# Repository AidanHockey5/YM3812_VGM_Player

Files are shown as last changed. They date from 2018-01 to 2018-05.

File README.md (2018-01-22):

# YM3812_VGM_Player
A Video Game Music player based on the YM3812 (OPL2) and Teensy 3.5.

You can view this project in action here:
https://www.youtube.com/watch?v=aLaUDFnNqQc

# Information about the main sound chips and VGM

The YM3812, AKA OPL2 was a staple FM soundchip of the early 1990's. It claim to fame was its inclusion on the Adlib and Soundblaster soundcards. OPL2 is THE FM sound of 1990's PC gaming.

VGM stands for Video Game Music, and it is a 44.1KHz logging format that stores real soundchip register information. My player will parse these files and send the data to the appropriate chips. You can learn more about the VGM file format here: http://www.smspower.org/Music/VGMFileFormat

http://www.smspower.org/uploads/Music/vgmspec170.txt?sid=58da937e68300c059412b536d4db2ca0

# Hook-up Guide

Teensy 3.5 | YM
------------ | -------------
23, 22, 21...17, 16 | D0-D7
34  | CS
33 | RD
32 | WR
31 | A0
30 | IC
29 | IRQ

The YM3812 requires a 3.579545 MHz signal to function properly. I just used a full-can crystal for this, but any clock source of that speed will work.
You will also need a Y3014B DAC IC along with an OP-amp (LM358).

# SD Card Information
The Teensy 3.5 has a built-in, high speed micro-SD card reader. You must format your SD card to Fat32 in order for this device to work correctly. Your SD card must only contain uncompressed .vgm files. VGZ FILES WILL NOT WORK! You may download .vgz files and use [7zip](http://www.7-zip.org/download.html) to extract the uncompressed file out of them. Vgm files on the SD card do not need to have the .vgm extension. As long as they contain valid, uncompressed vgm data, they will be read by the program regardless of their name.
You can find VGM files by Googling "myGameName VGM," or by checking out sites like http://vgmrips.net/packs/

# Control Over Serial
You can use a serial connection to control playback features. The commands are as follows:

Command | Result
------------ | -------------
\+ | Next Track
\- | Previous Track
\* | Random Track
\/ | Toggle Shuffle Mode
\. | Toggle Song Looping
r: | Request song

A song request is formatted as follows: ```r:mySongFile.vgm```
Once a song request is sent through the serial console, an attempt will be made to open that song file. The file must exist on the Teensy's SD card, and spelling/capitalization must be correct.
Need an easy-to-use serial console? [I've made one here.](https://github.com/AidanHockey5/OpenArduinoSerialConsole)

# Schematic
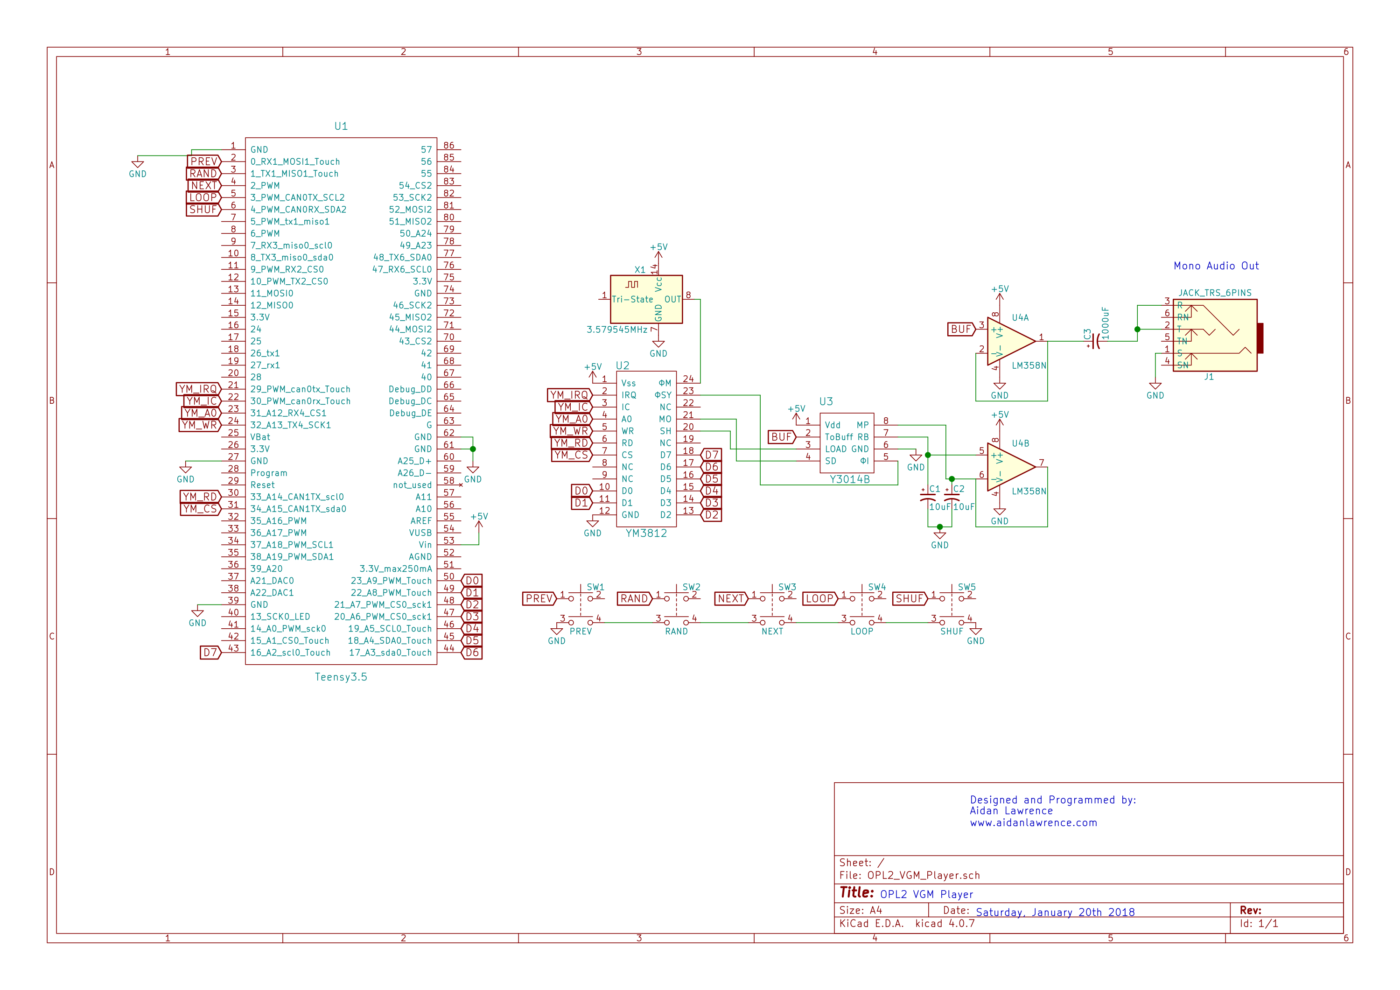
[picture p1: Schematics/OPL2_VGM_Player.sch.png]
Schematic


[PDF](https://github.com/AidanHockey5/YM3812_VGM_Player/raw/master/Schematics/OPL2_VGM_Player.pdf)

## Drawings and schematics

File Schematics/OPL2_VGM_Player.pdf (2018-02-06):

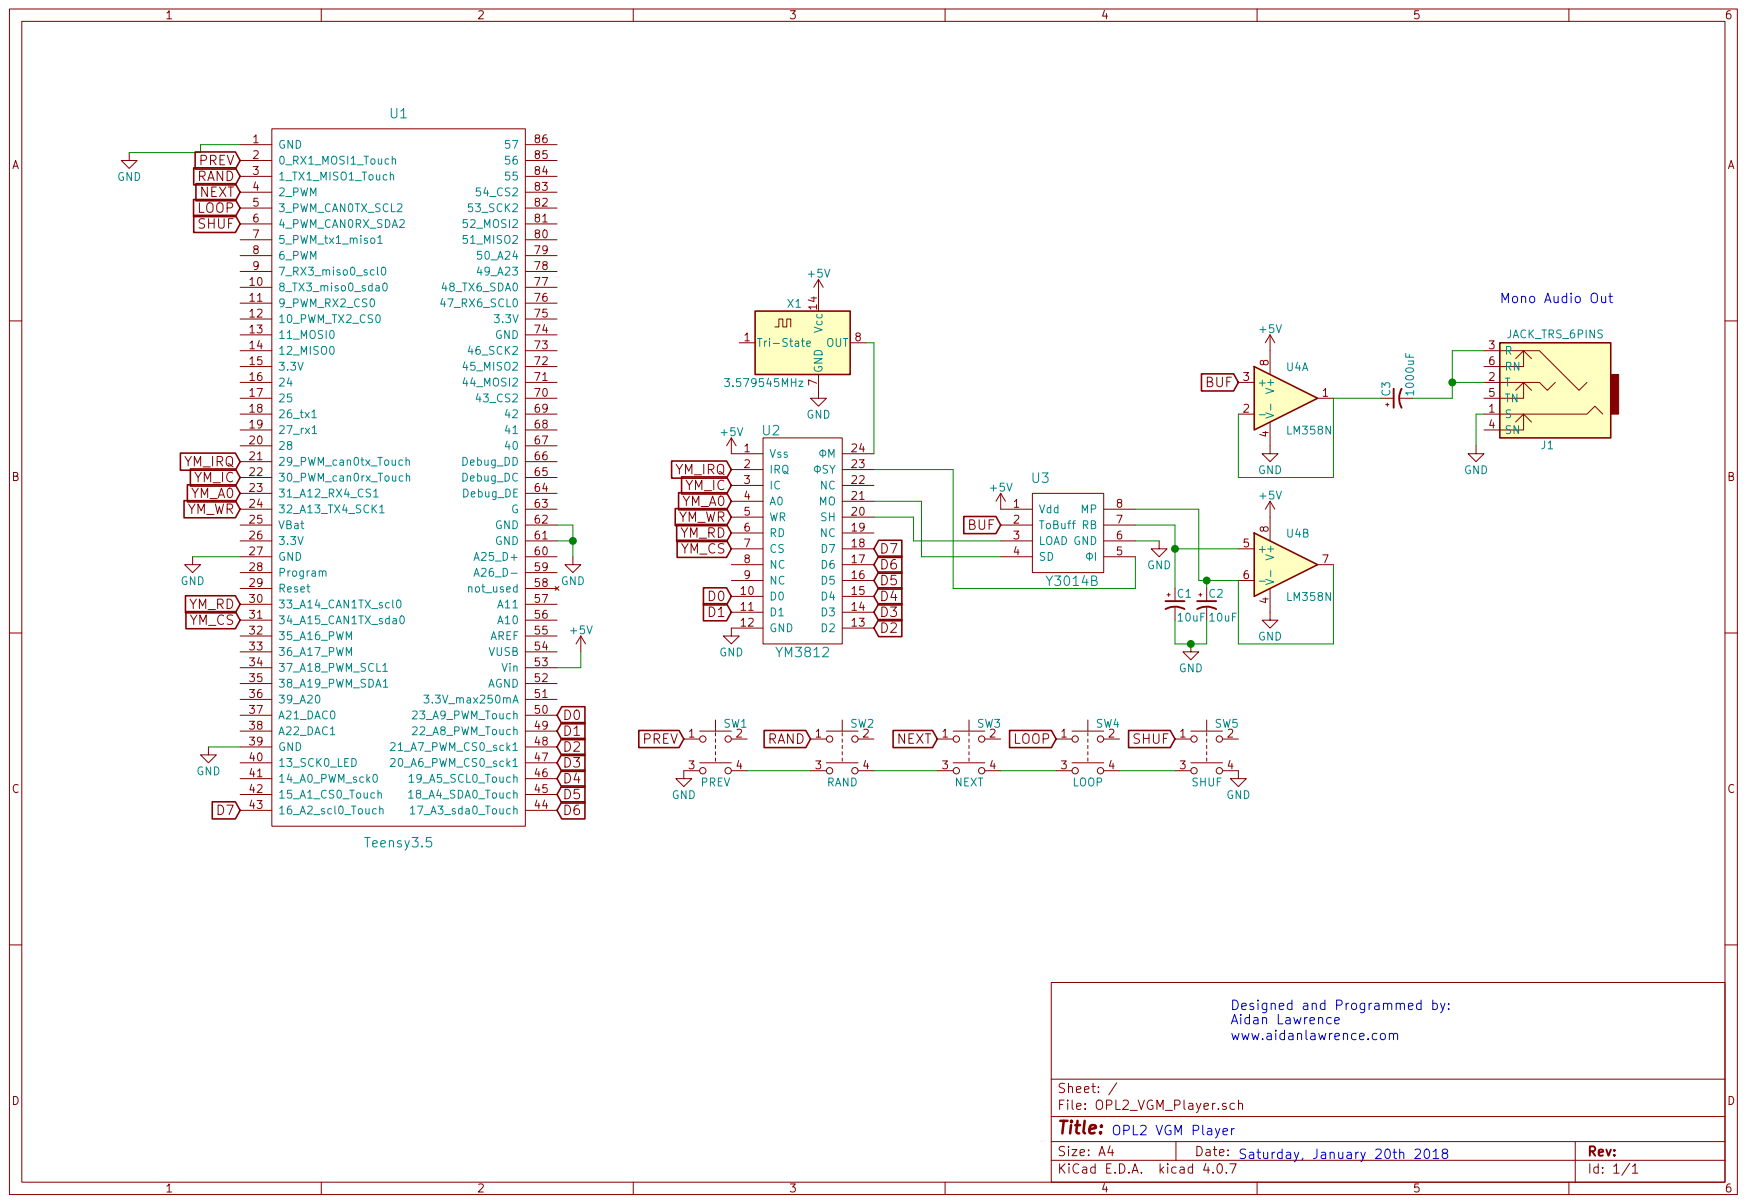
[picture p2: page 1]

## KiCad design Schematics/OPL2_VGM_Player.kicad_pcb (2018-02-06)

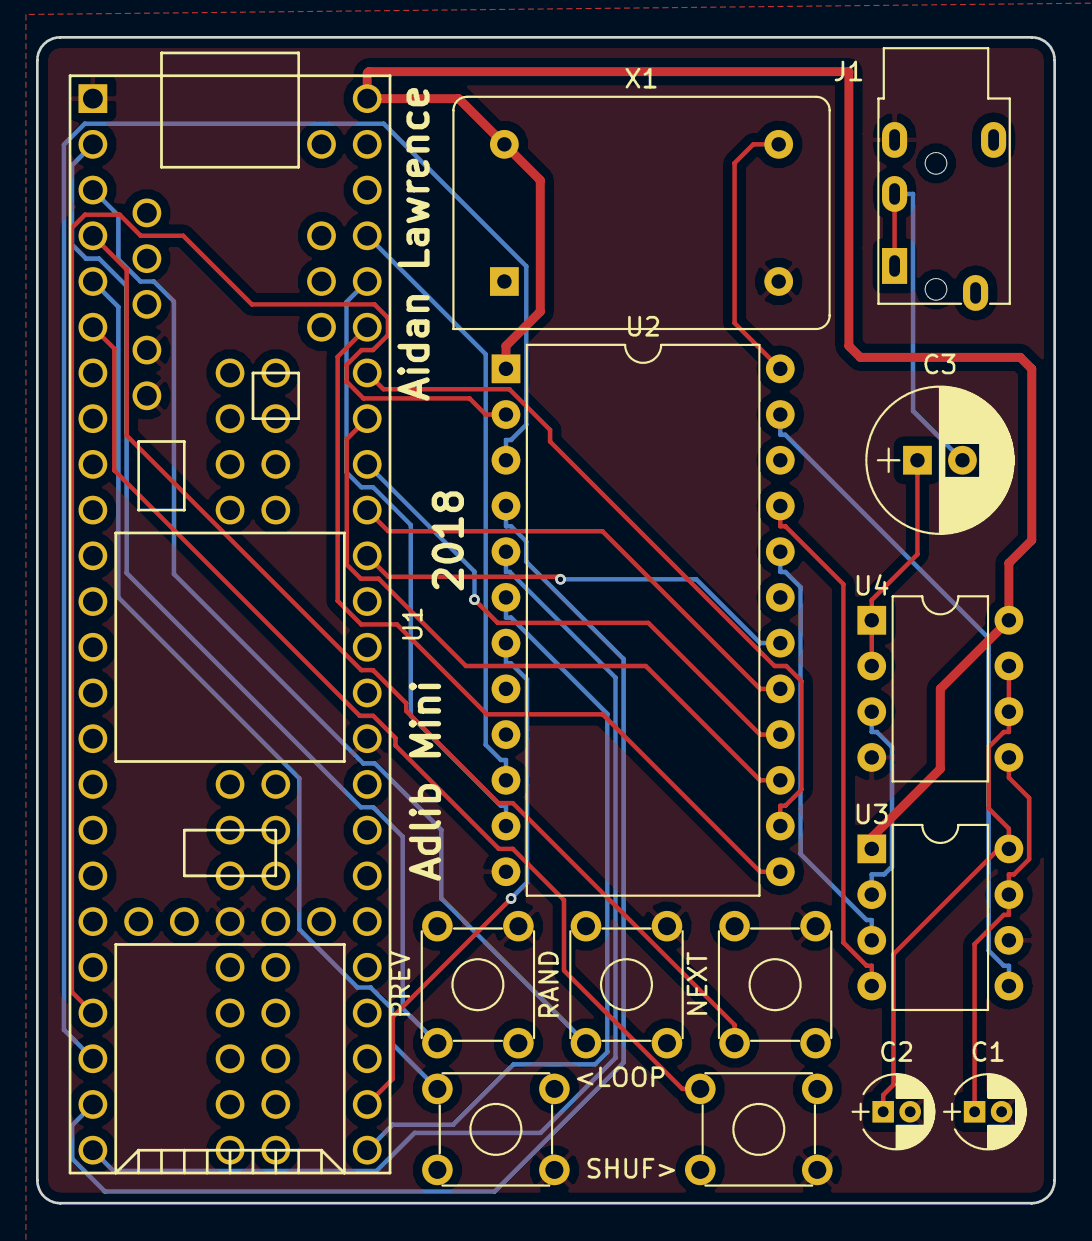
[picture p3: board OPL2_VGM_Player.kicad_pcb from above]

Board: 2 copper layers, 56.5 x 64.8 mm, 14 parts (0 on the bottom side), 30 nets.

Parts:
<LOOP: LOOP; SW_TH_Tactile_Omron_B3F-10xx
C1, C2: 10uF; CP_Radial_D4.0mm_P1.50mm
C3: 1000uF; CP_Radial_D8.0mm_P2.50mm
J1: JACK_TRS_6PINS; PJ320E_3.5mm_Jack
NEXT: NEXT; SW_TH_Tactile_Omron_B3F-10xx
PREV: PREV; SW_TH_Tactile_Omron_B3F-10xx
RAND: RAND; SW_TH_Tactile_Omron_B3F-10xx
SHUF>: SHUF; SW_TH_Tactile_Omron_B3F-10xx
U1: Teensy3.5; Teensy35_36
U2: YM3812; DIP-24_W15.24mm
U3: Y3014B; DIP-8_W7.62mm
U4: LM358N; DIP-8_W7.62mm
X1: 3.579545MHz; Oscillator_DIP-14

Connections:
+5V: U1.53, U2.1, U3.1, U4.8, X1.14
BUF: U3.2, U4.3
D0: U1.50, U2.10
D1: U1.49, U2.11
D2: U1.48, U2.13
D3: U1.47, U2.14
D4: U1.46, U2.15
D5: U1.45, U2.16
D6: U1.44, U2.17
D7: U1.43, U2.18
GND: <LOOP.4, C1.2, C2.2, J1.3, NEXT.4, PREV.4, RAND.4, SHUF>.4, U1.1, U1.27, U1.39, U1.61, U1.62, U2.12, U3.6, U4.4, X1.7
LOOP: <LOOP.1, U1.5
NEXT: NEXT.1, U1.4
unnamed: C1.1, U3.7, U4.5
unnamed: C2.1, U3.8, U4.6, U4.7
unnamed: C3.1, U4.1, U4.2
unnamed: C3.2, J1.1, J1.2
unnamed: U2.20, U3.3
unnamed: U2.21, U3.4
unnamed: U2.23, U3.5
unnamed: U2.24, X1.8
PREV: PREV.1, U1.2
RAND: RAND.1, U1.3
SHUF: SHUF>.1, U1.6
YM_A0: U1.23, U2.4
YM_CS: U1.31, U2.7
YM_IC: U1.22, U2.3
YM_IRQ: U1.21, U2.2
YM_RD: U1.30, U2.6
YM_WR: U1.24, U2.5

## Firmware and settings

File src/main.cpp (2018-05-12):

#include <Arduino.h>
#include "SdFat.h"
#include "YM3812.h"

int YM_Datapins[8] = {23, 22, 21, 20, 19, 18, 17, 16};

const int YM_CS = 34;
const int YM_RD = 33;
const int YM_WR = 32;
const int YM_A0 = 31;
const int YM_IC = 30; 
const int YM_IRQ = 29;

YM3812 ym3812(YM_Datapins, YM_CS, YM_RD, YM_WR, YM_A0, YM_IRQ, YM_IC);

const int prev_btn = 0;
const int rand_btn = 1;
const int next_btn = 2;
const int loop_btn = 3;
const int shuf_btn = 4;

SdFatSdio SD;
File vgm;

//Buffer & file stream
const unsigned int MAX_CMD_BUFFER = 1;
unsigned char cmdBuffer[MAX_CMD_BUFFER];
uint32_t bufferPos = 0;
const unsigned int MAX_FILE_NAME_SIZE = 1024;
char fileName[MAX_FILE_NAME_SIZE];
unsigned char cmd = 0;
uint16_t numberOfFiles = 0;
int32_t currentFileNumber = 0;


//Timing Variables
float singleSampleWait = 0;
const int sampleRate = 44100; //44100 standard
const float WAIT60TH = ((1000.0 / (sampleRate/(float)735))*1000);
const float WAIT50TH = ((1000.0 / (sampleRate/(float)882))*1000);
uint32_t waitSamples = 0;
unsigned long preCalced8nDelays[16];
unsigned long preCalced7nDelays[16];
unsigned long lastWaitData61 = 0;
unsigned long cachedWaitTime61 = 0;
unsigned long pauseTime = 0;
unsigned long startTime = 0;

//Song Data Variables
uint32_t loopOffset = 0;
uint16_t loopCount = 0;
uint16_t nextSongAfterXLoops = 3;
enum PlayMode {LOOP, PAUSE, SHUFFLE, IN_ORDER};
PlayMode playMode = SHUFFLE;

//GD3 Data
String trackTitle;
String gameName;
String systemName;
String gameDate;


void FillBuffer()
{
    vgm.readBytes(cmdBuffer, MAX_CMD_BUFFER);
    //Serial.print("File location: "); Serial.println(vgm.position(), HEX);
}

unsigned char GetByte()
{
  if(bufferPos == MAX_CMD_BUFFER)
  {
    bufferPos = 0;
    FillBuffer();
  }
  return cmdBuffer[bufferPos++];
}

uint32_t ReadBuffer32() //Read 32 bit value from buffer
{
  byte v0 = GetByte();
  byte v1 = GetByte();
  byte v2 = GetByte();
  byte v3 = GetByte();
  return uint32_t(v0 + (v1 << 8) + (v2 << 16) + (v3 << 24));
}

uint32_t ReadSD32() //Read 32 bit value straight from SD card
{
  byte v0 = vgm.read();
  byte v1 = vgm.read();
  byte v2 = vgm.read();
  byte v3 = vgm.read();
  return uint32_t(v0 + (v1 << 8) + (v2 << 16) + (v3 << 24));
}

void ClearBuffers()
{
  bufferPos = 0;
  for(int i = 0; i < MAX_CMD_BUFFER; i++)
    cmdBuffer[i] = 0;
}

void RemoveSVI() //Sometimes, Windows likes to place invisible files in our SD card without asking... GTFO!
{
  File nextFile;
  nextFile.openNext(SD.vwd(), O_READ);
  char name[MAX_FILE_NAME_SIZE];
  nextFile.getName(name, MAX_FILE_NAME_SIZE);
  String n = String(name);
  if(n == "System Volume Information")
  {
      if(!nextFile.rmRfStar())
        Serial.println("Failed to remove SVI file");
  }
  SD.vwd()->rewind();
  nextFile.close();
}

void ClearTrackData()
{
  for(int i = 0; i < MAX_FILE_NAME_SIZE; i++)
    fileName[i] = 0;
  trackTitle = "";
  gameName = "";
  systemName = "";
  gameDate = "";
}

uint32_t EoFOffset = 0;
uint32_t VGMVersion = 0;
uint32_t GD3Offset = 0;
void GetHeaderData() //Scrape off the important VGM data from the header, then drop down to the GD3 area for song info data
{
  ReadBuffer32(); //V - G - M 0x00->0x03
  EoFOffset = ReadBuffer32(); //End of File offset 0x04->0x07
  VGMVersion = ReadBuffer32(); //VGM Version 0x08->0x0B
  for(int i = 0x0C; i<0x14; i++)GetByte(); //Skip 0x0C->0x14
  GD3Offset = ReadBuffer32(); //GD3 (song info) data offset 0x14->0x17

  uint32_t bufferReturnPosition = vgm.position();
  vgm.seek(0);
  vgm.seekCur(GD3Offset+0x14);
  uint32_t GD3Position = 0x00;
  ReadSD32(); GD3Position+=4;  //G - D - 3
  ReadSD32(); GD3Position+=4;  //Version data
  uint32_t dataLength = ReadSD32(); //Get size of data payload
  GD3Position+=4;

  String rawGD3String;
  // Serial.print("DATA LENGTH: ");
  // Serial.println(dataLength);

  for(int i = 0; i<dataLength; i++) //Convert 16-bit characters to 8 bit chars. This may cause issues with non ASCII characters. (IE Japanese chars.)
  {
    char c1 = vgm.read();
    char c2 = vgm.read();
    if(c1 == 0 && c2 == 0)
      rawGD3String += '\n';
    else
      rawGD3String += char(c1);
  }
  GD3Position = 0;

  while(rawGD3String[GD3Position] != '\n') //Parse out the track title.
  {
    trackTitle += rawGD3String[GD3Position];
    GD3Position++;
  }
  GD3Position++;

  while(rawGD3String[GD3Position] != '\n') GD3Position++; //Skip Japanese track title.
  GD3Position++;
  while(rawGD3String[GD3Position] != '\n') //Parse out the game name.
  {
    gameName += rawGD3String[GD3Position];
    GD3Position++;
  }
  GD3Position++;
  while(rawGD3String[GD3Position] != '\n') GD3Position++;//Skip Japanese game name.
  GD3Position++;
  while(rawGD3String[GD3Position] != '\n') //Parse out the system name.
  {
    systemName += rawGD3String[GD3Position];
    GD3Position++;
  }
  GD3Position++;
  while(rawGD3String[GD3Position] != '\n') GD3Position++;//Skip Japanese system name.
  GD3Position++;
  while(rawGD3String[GD3Position] != '\n') GD3Position++;//Skip English authors
  GD3Position++;
  // while(rawGD3String[GD3Position] != 0) //Parse out the music authors (I skipped this since it sometimes produces a ton of data! Uncomment this, comment skip, add vars if you want this.)
  // {
  //   musicAuthors += rawGD3String[GD3Position];
  //   GD3Position++;
  // }
  while(rawGD3String[GD3Position] != '\n') GD3Position++;//Skip Japanese authors.
  GD3Position++;
  while(rawGD3String[GD3Position] != '\n') //Parse out the game date
  {
    gameDate += rawGD3String[GD3Position];
    GD3Position++;
  }
  GD3Position++;
  Serial.println(trackTitle);
  Serial.println(gameName);
  Serial.println(systemName);
  Serial.println(gameDate);
  Serial.println("");
  vgm.seek(bufferReturnPosition); //Send the file seek back to the original buffer position so we don't confuse our program.
  waitSamples = ReadBuffer32(); //0x18->0x1B : Get wait Samples count
  loopOffset = ReadBuffer32();  //0x1C->0x1F : Get loop offset Postition
  for(int i = 0; i<5; i++) ReadBuffer32(); //Skip right to the VGM data offset position;
  uint32_t vgmDataOffset = ReadBuffer32();
  if(vgmDataOffset == 0 || vgmDataOffset == 12) //VGM starts at standard 0x40
  {
    ReadBuffer32(); ReadBuffer32();
  }
  else
  {
    for(int i = 0; i < vgmDataOffset-4; i++) GetByte();  //VGM starts at different data position (Probably VGM spec 1.7+)
  }
  //Offset manually set to -4 due to overshooting the data offset. This does not seem normal and will need to be fixed.
  //Serial.println("Starting postion: "); Serial.println(vgm.position(), HEX);
}

enum StartUpProfile {FIRST_START, NEXT, PREVIOUS, RNG, REQUEST};
void StartupSequence(StartUpProfile sup, String request = "")
{
  File nextFile;
  ClearTrackData();
  switch(sup)
  {
    case FIRST_START:
    {
      nextFile.openNext(SD.vwd(), O_READ);
      nextFile.getName(fileName, MAX_FILE_NAME_SIZE);
      nextFile.close();
      currentFileNumber = 0;
    }
    break;
    case NEXT:
    {
      if(currentFileNumber+1 >= numberOfFiles)
      {
          SD.vwd()->rewind();
          currentFileNumber = 0;
      }
      else
          currentFileNumber++;
      nextFile.openNext(SD.vwd(), O_READ);
      nextFile.getName(fileName, MAX_FILE_NAME_SIZE);
      nextFile.close();
    }
    break;
    case PREVIOUS:
    {
      if(currentFileNumber != 0)
      {
        currentFileNumber--;
        SD.vwd()->rewind();
        for(int i = 0; i<=currentFileNumber; i++)
        {
          nextFile.close();
          nextFile.openNext(SD.vwd(), O_READ);
        }
        nextFile.getName(fileName, MAX_FILE_NAME_SIZE);
        nextFile.close();
      }
      else
      {
        currentFileNumber = numberOfFiles-1;
        SD.vwd()->rewind();
        for(int i = 0; i<=currentFileNumber; i++)
        {
          nextFile.close();
          nextFile.openNext(SD.vwd(), O_READ);
        }
        nextFile.getName(fileName, MAX_FILE_NAME_SIZE);
        nextFile.close();
      }
    }
    break;
    case RNG:
    {
      randomSeed(micros());
      uint16_t randomFile = currentFileNumber;
      while(randomFile == currentFileNumber)
        randomFile = random(numberOfFiles-1);
      currentFileNumber = randomFile;
      SD.vwd()->rewind();
      nextFile.openNext(SD.vwd(), O_READ);
      {
        for(int i = 0; i<randomFile; i++)
        {
          nextFile.close();
          nextFile.openNext(SD.vwd(), O_READ);
        }
      }
      nextFile.getName(fileName, MAX_FILE_NAME_SIZE);
      nextFile.close();
    }
    break;
    case REQUEST:
    {
      SD.vwd()->rewind();
      bool fileFound = false;
      Serial.print("REQUEST: ");Serial.println(request);
      for(int i = 0; i<numberOfFiles; i++)
      {
        nextFile.close();
        nextFile.openNext(SD.vwd(), O_READ);
        nextFile.getName(fileName, MAX_FILE_NAME_SIZE);
        String tmpFN = String(fileName);
        tmpFN.trim();
        if(tmpFN == request.trim())
        {
          currentFileNumber = i;
          fileFound = true;
          break;
        }
      }
      nextFile.close();
      if(fileFound)
      {
        Serial.println("File found!");
      }
      else
      {
        Serial.println("ERROR: File not found! Continuing with current song.");
        return;
      }
    }
    break;
  }
  ym3812.Reset();
  waitSamples = 0;
  loopOffset = 0;
  lastWaitData61 = 0;
  cachedWaitTime61 = 0;
  pauseTime = 0;
  startTime = 0;
  loopCount = 0;
  cmd = 0;
  ClearBuffers();
  Serial.print("Current file number: "); Serial.print(currentFileNumber+1); Serial.print("/"); Serial.println(numberOfFiles);
  if(vgm.isOpen())
    vgm.close();
  vgm = SD.open(fileName, FILE_READ);
  if(!vgm)
    Serial.println("File open failed!");
  else
    Serial.println("Opened successfully...");
  FillBuffer();
  GetHeaderData();
  singleSampleWait = ((1000.0 / (sampleRate/(float)1))*1000);

    for(int i = 0; i<16; i++)
    {
      if(i == 0)
      {
        preCalced8nDelays[i] = 0;
        preCalced7nDelays[i] = 1;
      }
      else
      {
        preCalced8nDelays[i] = ((1000.0 / (sampleRate/(float)i))*1000);
        preCalced7nDelays[i] = ((1000.0 / (sampleRate/(float)i+1))*1000);
      }
    }
    delay(1000);
}

void setup()
{
    pinMode(prev_btn, INPUT_PULLUP);
    pinMode(rand_btn, INPUT_PULLUP);
    pinMode(next_btn, INPUT_PULLUP);
    pinMode(loop_btn, INPUT_PULLUP);
    pinMode(shuf_btn, INPUT_PULLUP);
    ym3812.Reset();
    if(!SD.begin())
    {
        Serial.println("Card Mount Failed");
        return;
    }
    RemoveSVI();
    File countFile;
    while ( countFile.openNext( SD.vwd(), O_READ ))
    {
      countFile.close();
      numberOfFiles++;
    }
    countFile.close();
    SD.vwd()->rewind();
    StartupSequence(FIRST_START);
}


bool tmp = false;
void loop()
{
  while(Serial.available() || Serial2.available())
  {
    bool USBorBluetooh = Serial.available();
    char serialCmd = USBorBluetooh ? Serial.read() : Serial2.read();
    switch(serialCmd)
    {
      case '+': //Next song
        StartupSequence(NEXT);
      break;
      case '-': //Previous Song
        StartupSequence(PREVIOUS);
      break;
      case '*': //Pick random song
        StartupSequence(RNG);
      break;
      case '/': //Toggle shuffle mode
        playMode == SHUFFLE ? playMode = IN_ORDER : playMode = SHUFFLE;
        playMode == SHUFFLE ? Serial.println("SHUFFLE ON") : Serial.println("SHUFFLE OFF");
        //DrawOledPage();
      break;
      case '.': //Toggle loop mode
        playMode == LOOP ? playMode = IN_ORDER : playMode = LOOP;
        playMode == LOOP ? Serial.println("LOOP ON") : Serial.println("LOOP OFF");
        //DrawOledPage();
      break;
      case 'r': //Song Request, format:  r:mySongFileName.vgm - An attempt will be made to find and open that file.
        String req = USBorBluetooh ? Serial.readString(1024) : Serial2.readString(1024);
        req.remove(0, 1); //Remove colon character
        StartupSequence(REQUEST, req);
      break;
    }
  }
  if(!digitalRead(next_btn))
    StartupSequence(NEXT);
  if(!digitalRead(prev_btn))
    StartupSequence(PREVIOUS);
  if(!digitalRead(rand_btn))
    StartupSequence(RNG);
  if(!digitalRead(shuf_btn))
  {
    playMode == SHUFFLE ? playMode = IN_ORDER : playMode = SHUFFLE;
    playMode == SHUFFLE ? Serial.println("SHUFFLE ON") : Serial.println("SHUFFLE OFF");
  }
  if(!digitalRead(loop_btn))
  {
    playMode == LOOP ? playMode = IN_ORDER : playMode = LOOP;
    playMode == LOOP ? Serial.println("LOOP ON") : Serial.println("LOOP OFF");   
  }
  if(loopCount >= nextSongAfterXLoops)
  {
    if(playMode == SHUFFLE)
      StartupSequence(RNG);
    if(playMode == IN_ORDER)
      StartupSequence(NEXT);
  }

  unsigned long timeInMicros = micros();
  if( timeInMicros - startTime <= pauseTime)
  {
    // Serial.print("timeInMicros"); Serial.print("\t"); Serial.println(timeInMicros);
    // Serial.print("DELTA"); Serial.print("\t"); Serial.println(timeInMicros - startTime);
    // Serial.print("startTime"); Serial.print("\t"); Serial.println(startTime);
    //Serial.print("pauseTime"); Serial.print("\t"); Serial.println(pauseTime);
    //delay(150);
    return;
  }
  
  cmd = GetByte();
  if(tmp == false)
  {
    tmp = true;
    Serial.print("First command:"); Serial.println(cmd, HEX);
  }
  switch(cmd)
  {
    case 0x5A:
    {
      uint8_t addr = GetByte();
      uint8_t data = GetByte();
      ym3812.SendDataPins(addr, data);
      break;
    }

    case 0x61:
    {
      //Serial.print("0x61 WAIT: at location: ");
      //Serial.print(parseLocation);
      //Serial.print("  -- WAIT TIME: ");
      uint32_t wait = 0;
      for ( int i = 0; i < 2; i++ )
      {
        wait += ( uint32_t( GetByte() ) << ( 8 * i ));
      }


    startTime = timeInMicros;
    pauseTime = ((1000.0 / (sampleRate/(float)wait))*1000);
    //delayMicroseconds(cachedWaitTime61);
    //delay(cachedWaitTime61);
    break;
    }
    case 0x62:
    startTime = timeInMicros;
    pauseTime = WAIT60TH;
    //delay(16.67);
    //delayMicroseconds(WAIT60TH); //Actual time is 16.67ms (1/60 of a second)
    break;
    case 0x63:
    startTime = timeInMicros;
    pauseTime = WAIT50TH;
    //delay(20);
    //delayMicroseconds(WAIT50TH); //Actual time is 20ms (1/50 of a second)
    break;
    case 0x70:
    case 0x71:
    case 0x72:
    case 0x73:
    case 0x74:
    case 0x75:
    case 0x76:
    case 0x77:
    case 0x78:
    case 0x79:
    case 0x7A:
    case 0x7B:
    case 0x7C:
    case 0x7D:
    case 0x7E:
    case 0x7F:
    {
      //Serial.println("0x7n WAIT");
      uint32_t wait = cmd & 0x0F;
      //Serial.print("Wait value: ");
      //Serial.println(wait);
      startTime = timeInMicros;
      pauseTime = preCalced7nDelays[wait];
      //delay(preCalced7nDelays[wait]);
    break;
    }
    case 0x66:
      if(loopOffset == 0)
        loopOffset = 64;
      loopCount++;
      vgm.seek(loopOffset-0x1C);
      FillBuffer();
      bufferPos = 0;
      break;
      
      default:
      Serial.print("Defaulted command: "); Serial.println(cmd, HEX);
      Serial.print("At: "); Serial.println(vgm.position()-1, HEX);
      break;

  }

}































//

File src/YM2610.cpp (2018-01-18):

#include "YM2610.h"
#include <Arduino.h>

YM2610::YM2610(int * dataPins, int * radPins, int * padPins, int CS, int RD, int WR, int A1, int A0, int IRQ, int IC)
{
    _dataPins = dataPins;
    _radPins = radPins;
    _padPins = padPins;
    _CS = CS;
    _RD = RD;
    _WR = WR;
    _A1 = A1;
    _A0 = A0;
    _IRQ = IRQ;
    _IC = IC;
    for(int i = 0; i<8; i++)
    {
        pinMode(*(_dataPins+i), OUTPUT);
        pinMode(*(_radPins+i), OUTPUT);
        pinMode(*(_padPins+i), OUTPUT);
    }

    pinMode(_CS, OUTPUT);
    pinMode(_RD, OUTPUT);
    pinMode(_WR, OUTPUT);
    pinMode(_A1, OUTPUT);
    pinMode(_A0, OUTPUT);
    pinMode(_IRQ, OUTPUT);
    pinMode(_IC, OUTPUT);

    digitalWrite(_CS, HIGH);
    digitalWrite(_RD, LOW);
    digitalWrite(_WR, LOW);
    digitalWrite(_A1, LOW);
    digitalWrite(_A0, LOW);
    digitalWrite(_IRQ, LOW);
    digitalWrite(_IC, LOW);
}

void YM2610::Reset()
{
    digitalWrite(_IC, LOW);
    delayMicroseconds(25);
    digitalWrite(_IC, HIGH);
}

void YM2610::WriteDataPins(unsigned char data) //Digital I/O
{
    for(int i=0; i<8; i++)
    {
      digitalWrite(*(_dataPins+i), ((data >> i)&1));
    }
}

void YM2610::WriteRADPins(unsigned char data) //ADPCM_A
{
    for(int i=0; i<8; i++)
    {
      digitalWrite(*(_radPins+i), ((data >> i)&1));
    }
}

void YM2610::WritePADPins(unsigned char data) //ADPCM_B
{
    for(int i=0; i<8; i++)
    {
      digitalWrite(*(_padPins+i), ((data >> i)&1));
    }
}

void YM2610::SendDataPins(unsigned char addr, unsigned char data, bool port) //port=0 for PORT0, port=1 for PORT1
{
        digitalWrite(_A1, port);
        digitalWrite(_A0, LOW);
        digitalWrite(_CS, LOW);
        WriteDataPins(addr);
        digitalWrite(_WR, LOW);
        delayMicroseconds(1); //Replace with 10 nS delay?
        digitalWrite(_WR, HIGH);
        digitalWrite(_CS, HIGH);
        delayMicroseconds(1); //Replace with 10 nS delay?
        digitalWrite(_A0, HIGH);
        digitalWrite(_CS, LOW);
        WriteDataPins(data);
        digitalWrite(_WR, LOW);
        delayMicroseconds(1); //Replace with 10 nS delay?
        digitalWrite(_WR, HIGH);
        digitalWrite(_CS, HIGH);
}

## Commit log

2018-01-19 Fixed typos and reduced song startup delay
    [main.cpp]
2018-01-21 Added schematics
    [OPL2_VGM_Player-B.Cu.gbr, OPL2_VGM_Player-B.Mask.gbr, OPL2_VGM_Player-B.Paste.gbr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]
2018-01-21 Added schematic image
2018-01-22 Updated schematics and PCB to support playback buttons.
    [OPL2_VGM_Player-B.Adhes.gbr, OPL2_VGM_Player-B.CrtYd.gbr, OPL2_VGM_Player-B.Cu.gbr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]
2018-02-06 Fixed jack GND on board and schematic. Added control button support
    [OPL2_VGM_Player-B.Adhes.gbr, OPL2_VGM_Player-B.CrtYd.gbr, OPL2_VGM_Player-B.Cu.gbr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]
2018-03-31 Added local schematic symbols
